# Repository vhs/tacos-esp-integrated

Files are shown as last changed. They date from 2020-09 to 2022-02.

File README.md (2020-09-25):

# TACOS ESP integrated

This is the integrated interlock and terminal TACOS reference implementation on ESP/embedded (Platform IO).

## TACOS

[TACOS](https://github.com/vhs/tacos/) is an integrated tool access control operations system.

## Usage

* Clone this repository: `git clone https://github.com/vhs/tacos-esp-integrated`
* Copy includes/config.sample.h to includes/config.h
  * Configure NODE_ID
  * Enable and/or disable LOCKOUT and/or AUTH_TERMINAL functionality
  * Configure wifi, NODE_SECRET, backend, NTP, IO and default settings as needed
    * NODE_SECRET is only needed for authentication
* Copy `platformio.sample.ini` to `platformio.ini`
* Configure boards as needed
* Compile and upload

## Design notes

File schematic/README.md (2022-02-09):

# Schematics

## TACOS-ESP-Integrated-Full

This is a schematic for the full TACOS-ESP-Integrated design, which includes arming and NFC functionality.

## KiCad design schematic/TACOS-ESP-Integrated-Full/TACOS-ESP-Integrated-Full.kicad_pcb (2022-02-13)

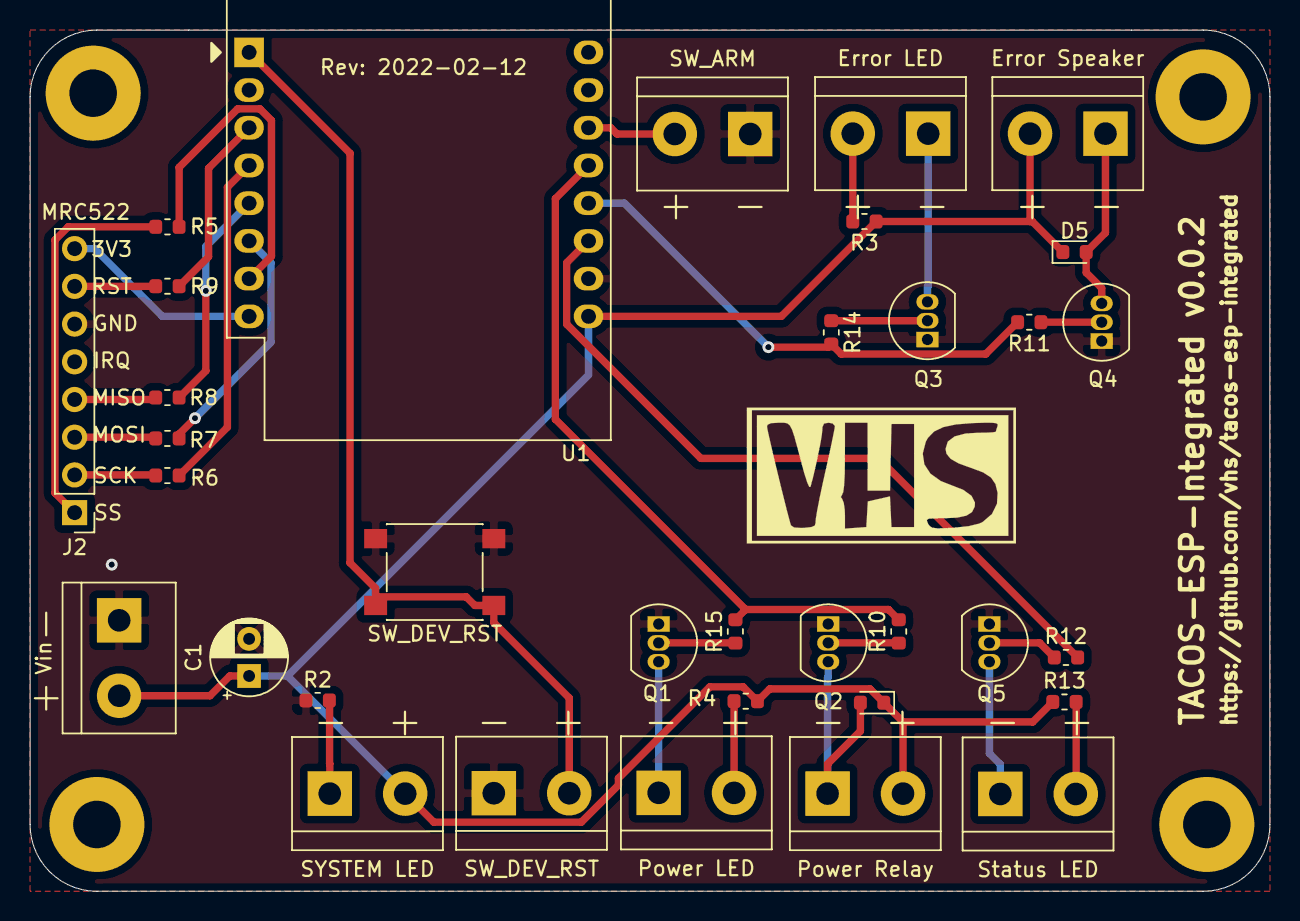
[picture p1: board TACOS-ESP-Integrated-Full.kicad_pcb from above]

Board: 2 copper layers, 83.5 x 58.0 mm, 38 parts (0 on the bottom side), 32 nets.

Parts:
C1: CP; CP_Radial_D5.0mm_P2.50mm
D1: SYSTEM LED; TerminalBlock_bornier-2_P5.08mm
D2: Error LED; TerminalBlock_bornier-2_P5.08mm
D3: Power LED; TerminalBlock_bornier-2_P5.08mm
D4: Status LED; TerminalBlock_bornier-2_P5.08mm
D5, D6: D; D_0603_1608Metric
H1, H2, H3, H4: MountingHole; MountingHole_3.2mm_M3_Pad
J1: Power Relay; TerminalBlock_bornier-2_P5.08mm
J2: MRC522; PinHeader_1x08_P2.54mm_Vertical
J4: Vin; TerminalBlock_bornier-2_P5.08mm
LS1: Error Speaker; TerminalBlock_bornier-2_P5.08mm
Q1, Q2, Q3, Q4, Q5: PN2222A; TO-92_Inline
R2, R3, R4, R12, R13: R330; R_0603_1608Metric
R5, R6, R7, R8, R9: R100; R_0603_1608Metric
R10: R4.7K; R_0603_1608Metric
R11, R14, R15: R1K; R_0603_1608Metric
SW1: SW_ARM; TerminalBlock_bornier-2_P5.08mm
SW2: SW_DEV_RST; TerminalBlock_bornier-2_P5.08mm
SW3: SW_DEV_RST; SW_SPST_PTS645
U1: WeMos_D1_mini; WEMOS_D1_mini_light

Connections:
+3V3: J2.8, U1.8
+5V: C1.1, D1.2, D5.1, D6.1, J1.2, J4.2, LS1.2, R3.1, R4.1, R13.1, U1.9
DEV_RST: SW2.2, SW3.2, U1.1
ERROR_NET: R11.2, R14.2, U1.12
GND: C1.2, J2.6, J4.1, Q1.1, Q2.1, Q3.1, Q4.1, Q5.1, R2.2, SW1.1, SW2.1, SW3.1, U1.10
MISO: R8.1, U1.5
MOSI: R7.1, U1.6
unnamed: D1.1, R2.1
unnamed: D2.1, Q3.3
unnamed: D2.2, R3.2
unnamed: D3.1, Q1.3
unnamed: D3.2, R4.2
unnamed: D4.1, Q5.3
unnamed: D4.2, R13.2
unnamed: D5.2, LS1.1, Q4.3
unnamed: D6.2, J1.1, Q2.3
unnamed: J2.1, R5.2
unnamed: J2.2, R6.2
unnamed: J2.3, R7.2
unnamed: J2.4, R8.2
unnamed: J2.7, R9.2
unnamed: Q1.2, R15.1
unnamed: Q2.2, R10.1
unnamed: Q3.2, R14.1
unnamed: Q4.2, R11.1
unnamed: Q5.2, R12.1
POWER_NET: R10.2, R15.2, U1.13
RST: R9.1, U1.3
SCK: R6.1, U1.4
SS: R5.1, U1.7
STATUS_NET: R12.2, U1.11
SWITCH: SW1.2, U1.14

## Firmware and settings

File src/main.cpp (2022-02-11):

#include "platform.h"

#include "tacos/io.h"
#include "tacos/lockout.h"
#include "tacos/terminal.h"
#include "tacos/network.h"
#include "tacos/state.h"
#include "tacos/time.h"
#include "tacos/utils.h"

void setup()
{
    Serial.begin(115200);
    delay(10);

    Serial.printf("Booting node %s...\n", NODE_ID);

    // prepare pins
    // Output
    pinMode(STATUS_PIN, OUTPUT);
    pinMode(ERROR_PIN, OUTPUT);
    pinMode(POWER_PIN, OUTPUT);

    // Input
#ifndef BUTTON_MODE
    pinMode(BUTTON_PIN, INPUT_PULLUP);
#else
    pinMode(BUTTON_PIN, BUTTON_MODE);
#endif

    // Clean up
    setToolOff();

    Serial.printf("Setting startup state...\n");
    forceState(STATE_STARTUP);

    Serial.printf("Starting network...\n");
    networkInit();

    Serial.printf("Starting time...\n");
    timeInit();

#ifdef AUTH_TERMINAL
    initTerminal();
#endif

    Serial.printf("Setting default state...\n");
    forceState(STATE_UNTRUSTED);
}

void loop()
{
    heartBeat();
    timeLoop();

#ifdef AUTH_TERMINAL
    terminalLoop();
#endif

#ifdef LOCKOUT
    lockoutLoop();
#endif

    applyState();
}

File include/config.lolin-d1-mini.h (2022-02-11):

#ifndef CONFIG_H
#define CONFIG_H

#include <TZ.h>

#ifndef NODE_ID
#define NODE_ID "vhs-tacos-lolin-d1-mini-test-1"
#endif

// #define LOCKOUT
// #define AUTH_TERMINAL

// Wireless
#define WIFI_NAME "WIFI-SSID"
#define WIFI_PASS "WIFI-PASS"

// Set the 
#ifdef AUTH_TERMINAL
#define NODE_SECRET "TERMINALSECRET"
#endif

// TACOS backend configuration
#define HTTPS_BACKEND
#define SERVER_API_URL "https://tacos.vanhack.ca/api"

// NTP configuration
#define NTP_SERVER "ca.pool.ntp.org"
#define NTP_TZ TZ_America_Vancouver

// Debug, this is usually off
// #define DEBUG 1

// Defaults
#define BLINK_DELAY 250
#define CONNECTION_RETRIES 50
#define DEBOUNCE_DELAY 50
#define LOOP_DELAY 500
#define NETWORK_DELAY 500

// IO settings
#define STATUS_PIN D0
#define ERROR_PIN D1
#define POWER_PIN D8

#define BUTTON_PIN D2
// #define BUTTON_MODE INPUT

#define SS_PIN D4
#define RST_PIN D3

#endif

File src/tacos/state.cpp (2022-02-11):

#include "platform.h"

#include "tacos/io.h"
#include "tacos/state.h"

// Block trying to arm in case switch was accidentally left on
int tool_armed = 0;
int block_retry = 1;

boolean state_dirty = false;

TACOS_STATES device_state = STATE_IDLE;

TACOS_STATES getState()
{
    return device_state;
}

void setState(TACOS_STATES new_state)
{
    if (new_state != device_state)
    {
        Serial.printf("STATE: Changing state from %i -> %i\n", device_state, new_state);
        device_state = new_state;
        state_dirty = true;
    }
}

void applyState(unsigned long max_delay)
{
    TACOS_STATES update_state = device_state;

    unsigned long start = millis();

    if (state_dirty)
    {
        switch (device_state)
        {
        case STATE_UNTRUSTED:
            Serial.printf("STATE: Untrusted\n");
            setBlockRetry();
            unsetToolArmed();
            break;
        case STATE_IDLE:
            Serial.printf("STATE: Idle\n");
            ledMultiBlink(STATUS_PIN, 1, 250);
            break;
        case STATE_QUERYING:
            Serial.printf("STATE: Querying\n");
            setStatusLedOn();
            break;
        case STATE_PRIMED:
            Serial.printf("STATE: Primed\n");
            ledMultiBlink(STATUS_PIN, 3, 125);
            break;
        case STATE_TOOL_ARMED:
            setErrorLedOff();
            ledMultiBlink(STATUS_PIN, 3, 125);
            unsetBlockRetry();
            setStatusLedOn();
            setToolArmed();
            setToolOn();
            ledMultiBlink(ERROR_PIN, 3, 125);
            Serial.printf("NOTICE: Tool enabled\n");
            break;
        case STATE_TOOL_SAFE:
            setPowerOff();
            setStatusLedOff();
            setErrorLedOff();
            unsetToolArmed();
            unsetBlockRetry();
            Serial.printf("NOTICE: Tool disabled\n");
            update_state = STATE_IDLE;
            break;
        case STATE_STARTUP:
            Serial.printf("Starting up\n");
            doAlternateBlink();
            setStatusLedOff();
            setErrorLedOff();
            break;
        case STATE_ERROR:
            Serial.printf("STATE: ERROR\n");
            ledMultiBlink(ERROR_PIN);
            setErrorLedOn();
            break;
        case STATE_TOOL_ERROR:
            Serial.printf("STATE: TOOL ERROR\n");
            ledMultiBlink(ERROR_PIN);
            setBlockRetry();
            setErrorLedOn();
            Serial.printf("ERROR: Error set\n");
            break;
        case STATE_CLEAR_TOOL_ERRORS:
            Serial.printf("STATE: CLEAR TOOL ERRORS\n");
            setErrorLedOff();
            ledMultiBlink(STATUS_PIN);
            unsetBlockRetry();
            Serial.printf("NOTICE: Error cleared\n");
            update_state = STATE_IDLE;
            break;
        case STATE_AUTH_SUCCESS:
            Serial.printf("STATE: Authenticated\n");
            setStatusLedOn();
            ledMultiBlink(ERROR_PIN, 1, 1000);
            setStatusLedOff();
            update_state = STATE_IDLE;
            break;
        case STATE_ERROR_AUTH:
        case STATE_AUTH_ERROR:
            Serial.printf("STATE: AUTH ERROR\n");
            errorSignal();
            update_state = STATE_IDLE;
            break;
        case STATE_ERROR_SERVER:
        case STATE_ERROR_NETWORK:
            Serial.printf("STATE: NETWORK ERROR\n");
            ledMultiBlink(ERROR_PIN, 6, 125);
            update_state = STATE_IDLE;
            break;
        };

        state_dirty = false;
    }

    setState(update_state);

    // Sleep for remaining time
    unsigned long end = millis();

    unsigned long duration = (end - start);
    long remainder = (long)(max_delay - duration);

    if (remainder > 0)
    {
        // Serial.printf("STATE: waiting for %li ms\n", remainder);
        delay(remainder);
    }
    // Serial.printf("STATE: nap time over!\n");
}

void forceState(TACOS_STATES new_state, unsigned long max_delay)
{
    setState(new_state);
    applyState(max_delay);
}

int getBlockRetry()
{
    return block_retry;
}

bool isBlockRetry()
{
    return block_retry == 1;
}

void setBlockRetry()
{
    block_retry = 1;
}

void unsetBlockRetry()
{
    block_retry = 0;
}

int getToolArmed()
{
    return tool_armed;
}

bool isToolArmed()
{
    return (tool_armed == 1);
}

void setToolArmed()
{
    Serial.println("setToolArmed");
    tool_armed = 1;
}

void unsetToolArmed()
{
    Serial.println("unsetToolArmed");
    tool_armed = 0;
}

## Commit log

2021-01-19 Schematic WIP
    [TACOS-ESP-Integrated.dsn, TACOS-ESP-Integrated.kicad_pcb, TACOS-ESP-Integrated.sch]
2021-01-19 Removed DSN file
    [TACOS-ESP-Integrated.dsn]
2021-01-20 Schematic updates
    [TACOS-ESP-Integrated.kicad_pcb, TACOS-ESP-Integrated.sch]
2022-02-07 Various: cleaned up/improved power states - also aligned server armed state data
2022-02-08 schematic: fully integrated with NFC
    [TACOS-ESP-Integrated-Full.dsn, TACOS-ESP-Integrated-Full.kicad_pcb, TACOS-ESP-Integrated-Full.sch]
2022-02-09 schematic/README: initial version
2022-02-09 schematic: update
    [TACOS-ESP-Integrated-Full.kicad_pcb, TACOS-ESP-Integrated-Full.sch, TACOS-ESP-Integrated.kicad_pcb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]
2022-02-11 Internal pull-up support for the button
    [TACOS-ESP-Integrated-Full.sch]
2022-02-11 Improved internal pull-up button input support
2022-02-11 Default internal pull-up button input support
2022-02-11 schematic: update - default to pulldown circuit
    [TACOS-ESP-Integrated-Full.sch]
2022-02-11 config.lolin-d1-mini.h: improved sample config
2022-02-11 Default internal pull-up button input
2022-02-12 schematic: update - routed
    [TACOS-ESP-Integrated-Full.dsn, TACOS-ESP-Integrated-Full.kicad_pcb]
2022-02-12 schematic: updates
    [TACOS-ESP-Integrated-Full.dsn, TACOS-ESP-Integrated-Full.kicad_pcb, TACOS-ESP-Integrated-Full.sch]
2022-02-13 schematic: updates - redid routing - redid logo
    [TACOS-ESP-Integrated-Full.dsn, TACOS-ESP-Integrated-Full.kicad_pcb]
